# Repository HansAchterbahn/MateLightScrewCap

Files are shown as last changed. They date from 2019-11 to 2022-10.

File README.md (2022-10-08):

# MateLight-ScrewCap
This Repo is based on the idea of [MateLight](http://matelight.rocks/) and improves it by a screw cap which is easy to install and easy to remove from the coasters.

In this Repository you can find
- PCB schematics and board layouts created in Eagle,
- PCB Gerber data (ready for manufacturing),
- a 3D model of the PCB and
- a 3D model of the screw cap (for 3D printer).

Have also a look to the following Repos with Python Code for our MateLight for use with a Raspberry Pi:
- https://git.cccgoe.de/jugendgruppe/matelight-effects
- https://git.cccgoe.de/jugendgruppe/matelight
- https://git.cccgoe.de/jugendgruppe/ml_simulator

A small presentation about the PCB assembly process can be found here:
- https://jugendgruppe.cccgoe.de/reveal_js/00-MateLightScrewCapSoldering.html
- https://jugendgruppe.cccgoe.de/projekte/matelight.html

*Fork me and have fun!*

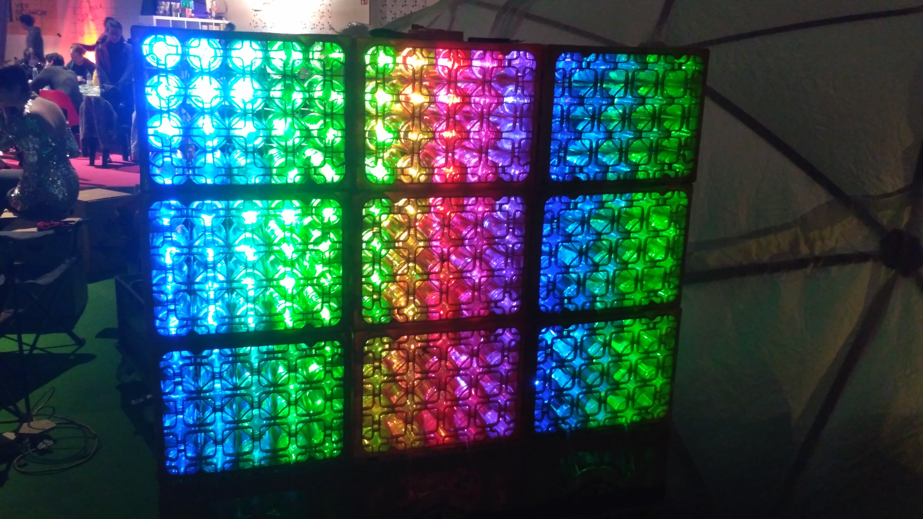
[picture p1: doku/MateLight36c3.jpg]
MateLight on 36c3

**MateLight of CCC youth group Göttingen at the 36c3 event 2019 in Leipzig**

## Power source

An APA102C LED consumes a maximum of 60 mA (red/green/blue each 20 mA). It is recommended to use a new 5 V / 1.4 mA power source for each 20 bottles(higher current delivery does not matter).

```
  ___  ^ 5V /    LED 1                            LED 19             LED 20             ___  ^ 5V /   LED 21
   |   | 1.4A  ___________  +5V            +5V   ___________  +5V    ___________ +5V     |   | 1.4A  ___________  +5V
   |   °------|    ___    |------         ------|    ___    |------|    ___    |--|      |   °------|    ___    |------
   |     GND  |   /   \   | GND            GND  |   /   \   | GND  |   /   \   | GND     |     GND  |   /   \   | GND
---°----------|  |     |  |------         ------|  |     |  |------|  |     |  |---------°----------|  |     |  |------
         CLK  |  |     |  | CLK     ...    CLK  |  |     |  | CLK  |  |     |  | CLK           CLK  |  |     |  | CLK     ...
------->------|  |     |  |------         ------|  |     |  |------|  |     |  |------------->------|  |     |  |------
         D    |   \___/   | D              D    |   \___/   | D    |   \___/   | D             D    |   \___/   | D
------->------|___________|------         ------|___________|------|___________|------------->------|___________|------
```

## 3D View (Fusion360)

Animated 3D STL model: [3d-model/MateLightScrewCap.stl](https://github.com/HansAchterbahn/MateLightScrewCap/blob/master/3d-model/MateLightScrewCap.stl)

__Top view__

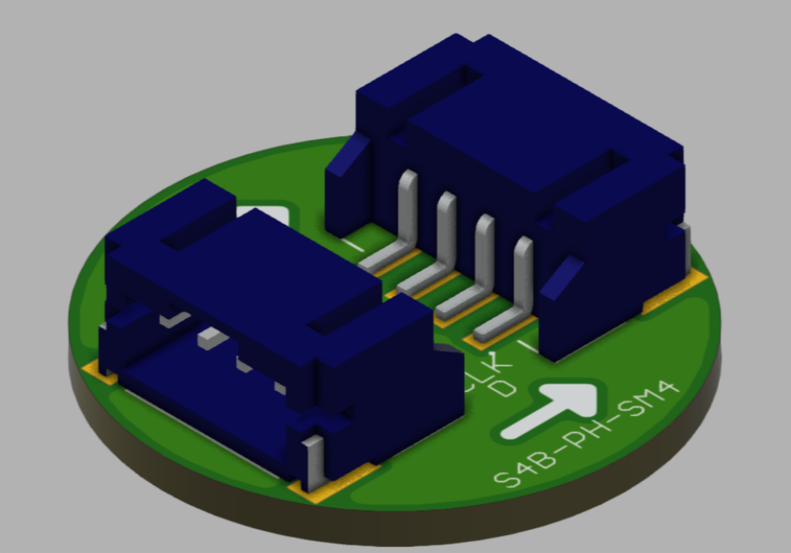
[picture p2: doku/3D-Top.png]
3D top view


__Bottom view__

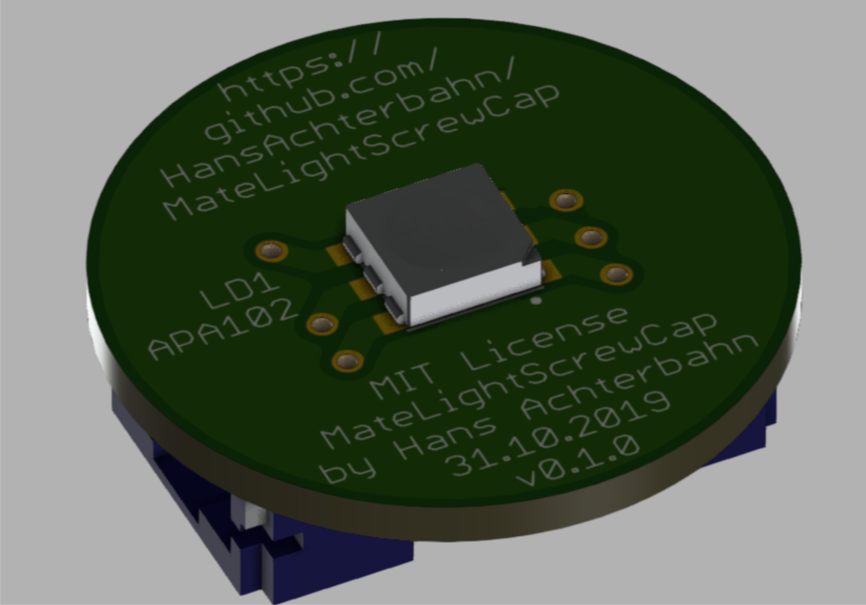
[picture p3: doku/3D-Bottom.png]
3D bottom view


## Schematic

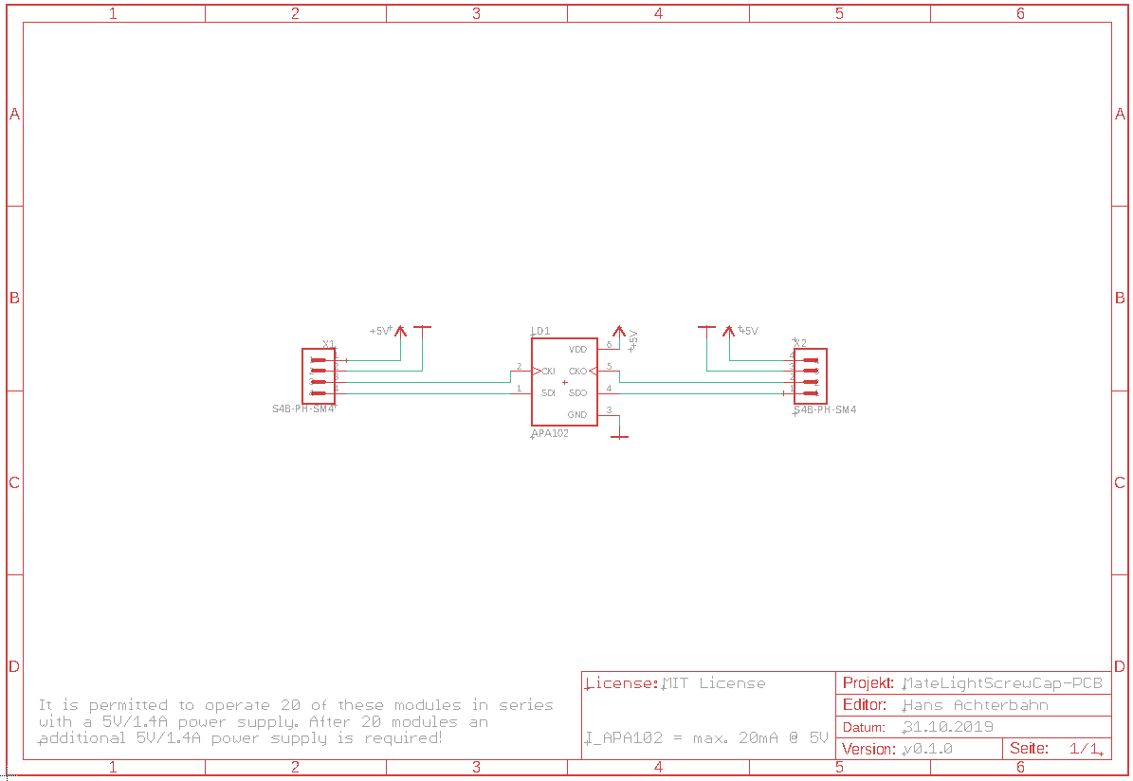
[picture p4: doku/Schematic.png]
Schematic view


## Board

__Top view__

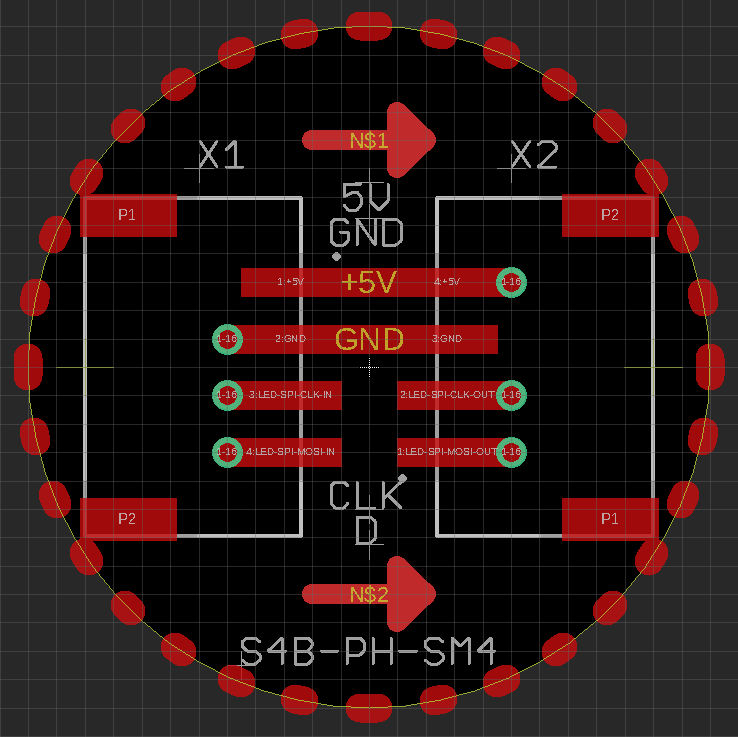
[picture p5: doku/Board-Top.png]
Board top view


__Bottom view__

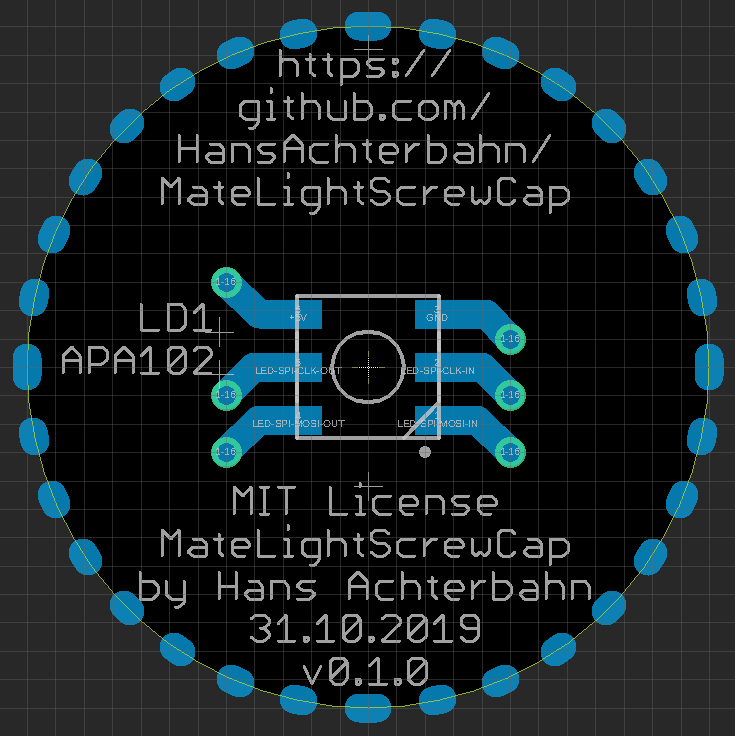
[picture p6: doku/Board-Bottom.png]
Board top view


## Manufacturing and assembly

__Manufactured PCBs__

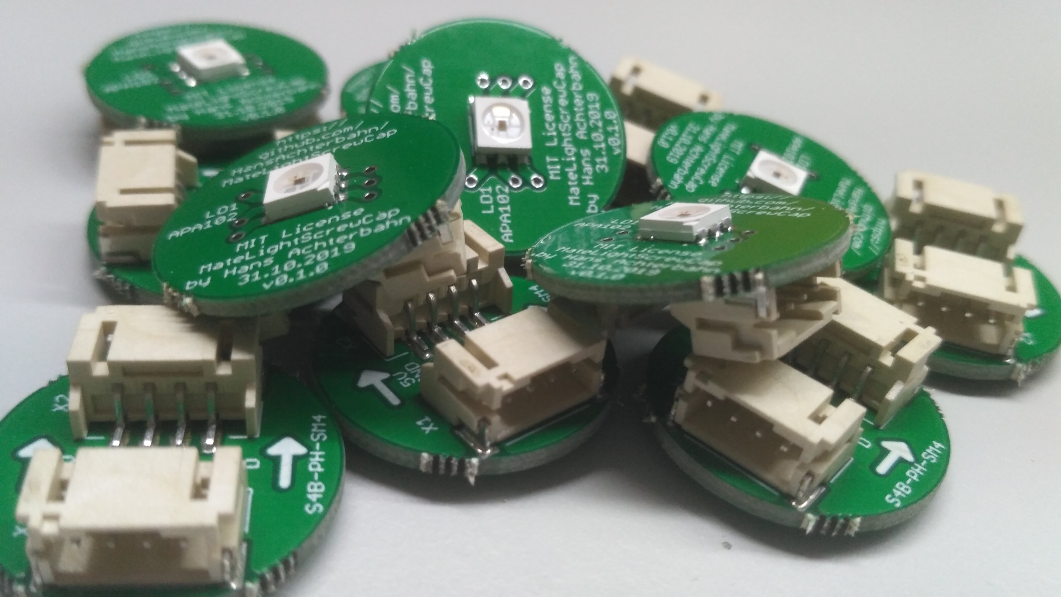
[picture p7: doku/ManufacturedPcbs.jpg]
Manufactured PCBs


__PCB with Cable__

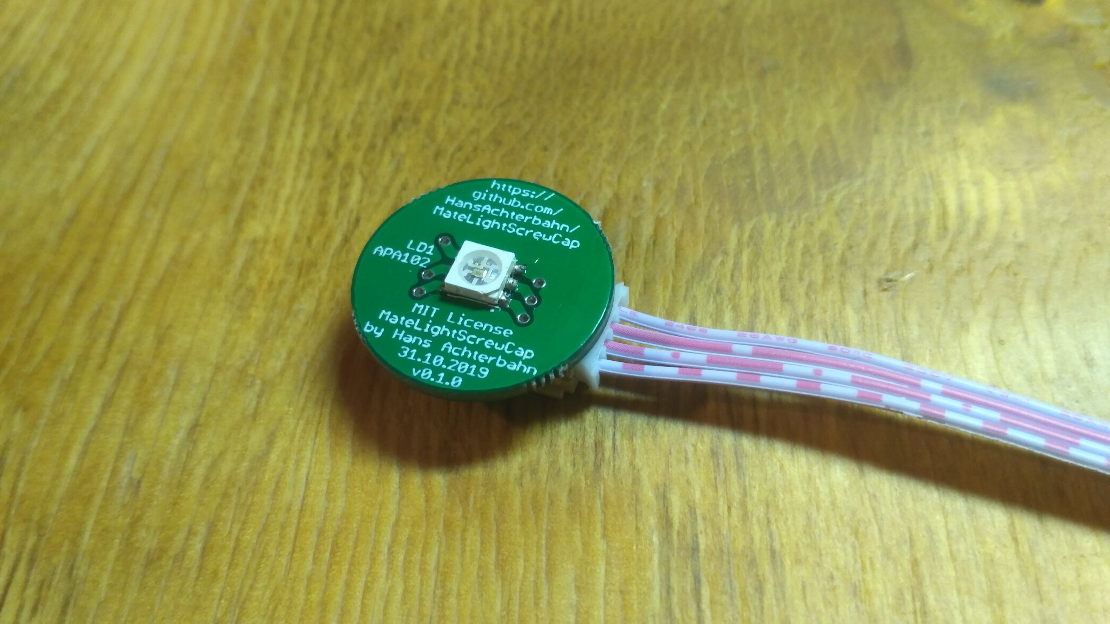
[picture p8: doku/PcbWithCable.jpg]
PCB with Cable


__Manufactured screw caps__

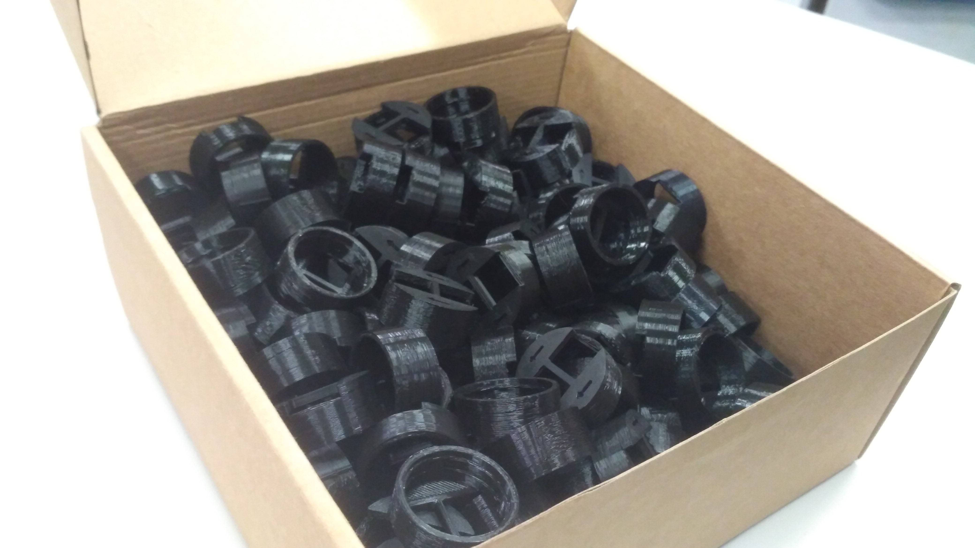
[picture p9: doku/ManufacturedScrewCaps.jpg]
Manufactured screw caps


__Assembled Mate bottle with PCB and screw cap__

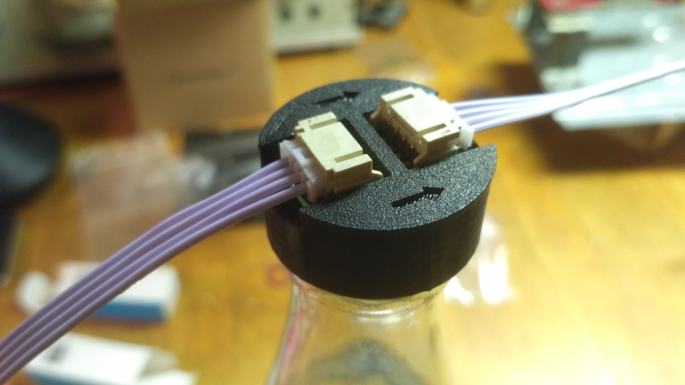
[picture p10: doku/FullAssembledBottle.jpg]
Assembled Mate bottle with PCB and screw cap


__Assembled Mate bottle with PCB and screw cap lighting red__

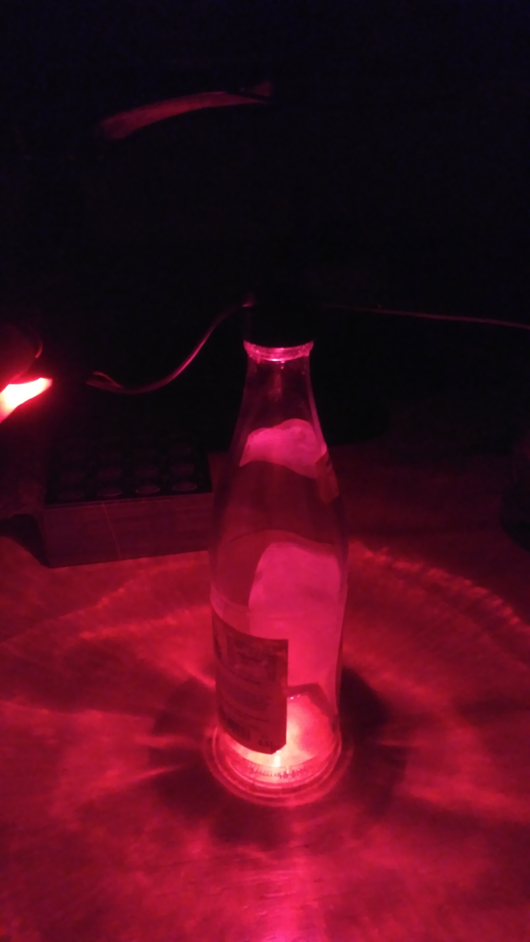
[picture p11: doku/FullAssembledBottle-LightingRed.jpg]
Assembled Mate bottle with PCB and screw cap lighting red


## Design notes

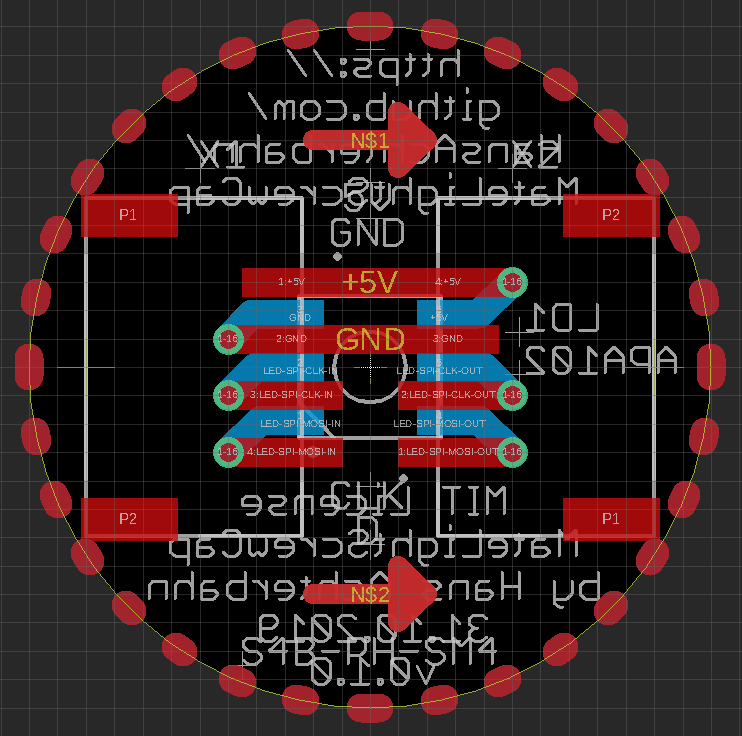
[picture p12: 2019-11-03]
doku/Board.png

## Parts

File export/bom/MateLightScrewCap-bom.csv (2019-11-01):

Qty | Value | Device | Package | Parts | Description | DESCRIPTION | DIGI-KEY | MF | MFN | MOUSER | RS-ONLINE
1 | APA102 | APA102APA102C-5050 | APA102C-5050 | LD1 | DotStar Micro LEDs (APA102–2020)- Smart SMD RGB LED - 100 pack
2 | S4B-PH-SM4 | S4B-PH-SM4-TB | JST_S4B-PH-SM4-TB | X1, X2 | JST - S4B-PH-SM4-TB | Socket | wire-board | male | PIN: 4 | 2mm | SMT

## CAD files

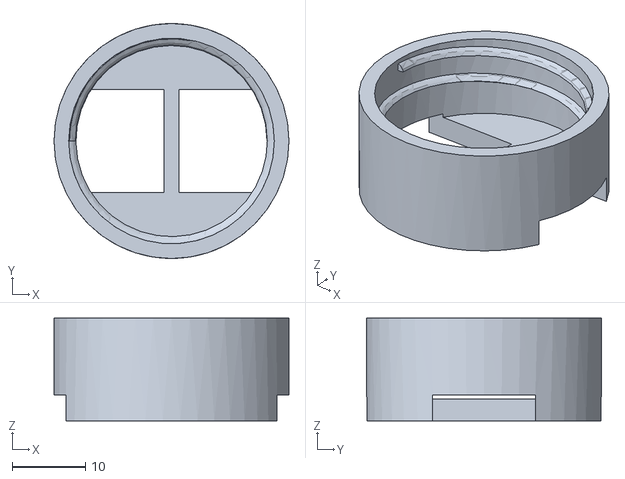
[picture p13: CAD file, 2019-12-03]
3d-model/MateLightScrewCap-Cap.stl
32.0 x 32.0 x 14.0

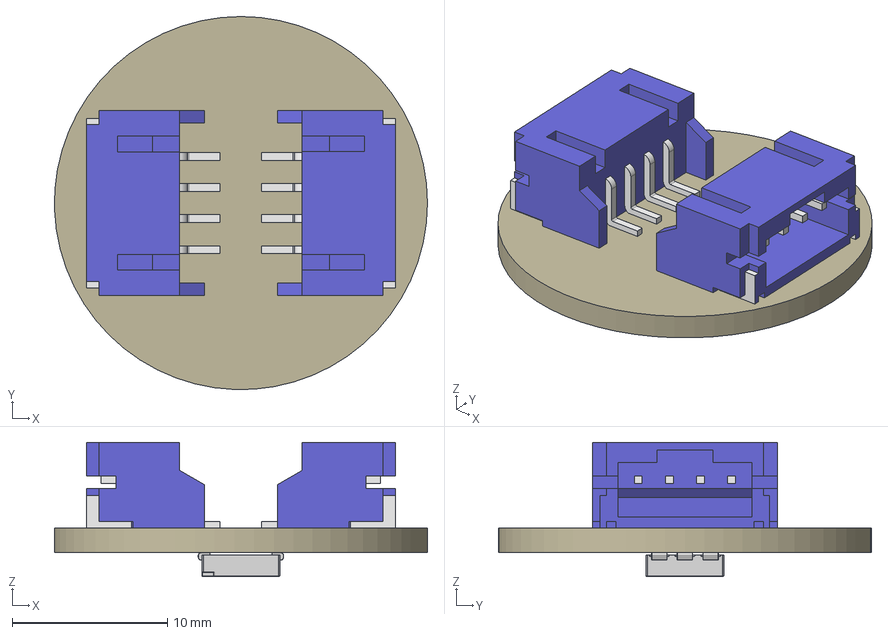
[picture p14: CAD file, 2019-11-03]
3d-model/MateLightScrewCap-Pcb.stp
24.0 x 24.0 x 8.63 mm
Board
APA102
S4B-PH-SM4-TB x 2

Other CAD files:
3d-model/MateLightScrewCap.stl

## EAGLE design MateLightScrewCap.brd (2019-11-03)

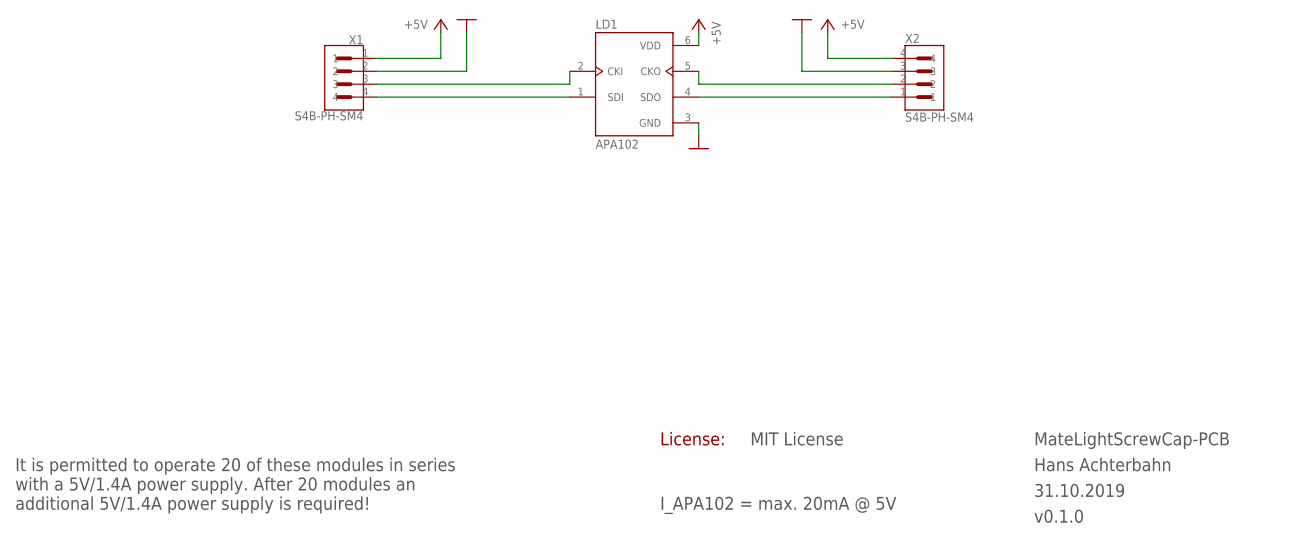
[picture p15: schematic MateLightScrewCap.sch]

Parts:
LD1: APA102; APA102C-5050
X1, X2: S4B-PH-SM4; JST_S4B-PH-SM4-TB

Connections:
+5V: LD1.6 (VDD), X1.1, X2.4
GND: LD1.3 (GND), X1.2, X2.3
LED-SPI-CLK-IN: LD1.2 (CKI), X1.3
LED-SPI-CLK-OUT: LD1.5 (CKO), X2.2
LED-SPI-MOSI-IN: LD1.1 (SDI), X1.4
LED-SPI-MOSI-OUT: LD1.4 (SDO), X2.1

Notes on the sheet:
I_APA102 = max. 20mA @ 5V
License:
It is permitted to operate 20 of these modules in series with a 5V/1.4A power supply. After 20 modules an additional 5V/1.4A power supply is required!

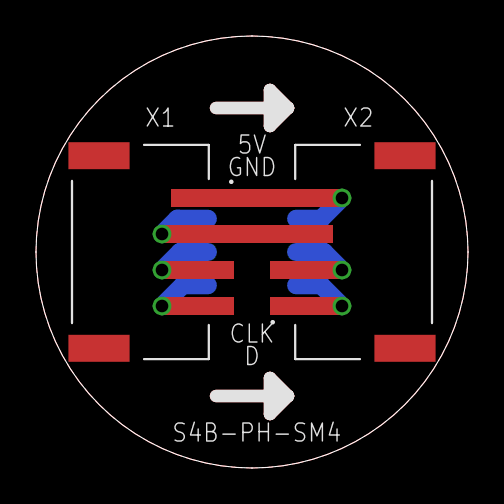
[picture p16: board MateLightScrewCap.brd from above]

Board: 2 copper layers, 24.0 x 24.0 mm, 3 parts (1 on the bottom side), 6 nets.

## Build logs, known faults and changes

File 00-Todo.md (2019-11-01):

# MateLightScrewCap: Todo

## Schematic

## Board

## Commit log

2019-10-31 Erster einfacher Prototyp fertig gestellt (Mit APA102 und Phoenix-1778780)
    [MateLightScrewCap.brd, MateLightScrewCap.sch]
2019-11-01 Connector getauscht: Phoenix-1778780 → JST S4B-PH-SM4-TB
    [MateLightScrewCap-bom.csv, MateLightScrewCap.brd, MateLightScrewCap.sch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]
2019-11-01 3D Modell und Screenshots von 3D Modell hinzugefügt
    [MateLightScrewCap.stl, MateLightScrewCap.stp]
2019-11-03 Konsistenzfehler behoben
    [MateLightScrewCap.brd, MateLightScrewCap.sch]
2019-12-03 3D Modell der Schraubverschluss Kappe hinzugefügt
    [MateLightScrewCap-Cap.stl, MateLightScrewCap-Pcb.stp]
2019-12-12 Readme: Added section "Power source"
2019-12-12 Repaired document consistency | correct current source properties
    [MateLightScrewCap.brd, MateLightScrewCap.sch]

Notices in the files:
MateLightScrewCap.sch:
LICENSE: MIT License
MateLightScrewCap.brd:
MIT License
